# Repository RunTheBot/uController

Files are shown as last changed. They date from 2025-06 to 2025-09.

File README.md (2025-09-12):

# µController

µController (micro controller) a tiny battery powered game controller design for one game...unrailed

This way, you can ruin friendships with unrailed anywhere, anytime.



final
# Features
- Hall effect PS4 style joysticks
- 2 Cherry MX keys for use and dash inputs
- Neopixel RGB LED under Cherry MX keys
- 5v boost converter for neopixel running off 3.7v battery
- USB-C charging port
- Battery charging
- Battery voltage sensor
- Battery level indicator
- Ultra low power mode
  - Deep sleep mode with wake on button press
  - Disables boost converter and neopixel
  - Disables Wireless connection
- Ultra Small: 79mm x 33mm
- Wireless

# BOM

| Name | Quantity | Single Unit Price | Total Price | URL/LCSC | Vendor (LCSC unless otheriwse indicated) | |
|---|---|---|---|---|---|---|
| Electronics | | | | | | |
| C5 0603 0.1uF | 3 | | $0.45 | C49678 | | |
| C3 0603 10uF | 1 | | $0.13 | C19702 | | |
| C4 0603 22uF | 1 | | $0.18 | C59461 | | |
| LED 0603 | 1 | | $0.32 | C965799 | | |
| SK6812MINI | 2 | | $0.37 | C5149201 | | |
| schottky diode | 2 | | | C85098 | | With NotAHackPad |
| BSS138 (Level Shifter) | 1 | | | C82045 | | With NotAHackPad |
| USB_C_Receptacle | 1 | | $0.38 | C2988369 | | |
| 2.2µH/±20%/1.5A Inductor | 1 | | $0.67 | C171762 | | |
| 0603 R5.1kΩ | 2 | | $0.09 | C2907044 | | |
| 0603 1.8M | 1 | | $0.08 | C2930026 | | |
| 0603 200k | 1 | | $0.12 | C105574 | | |
| 0603 120Ω | 1 | | $0.13 | C114640 | | |
| 0603 10K | 3 | | | C98220 | With NotAHackPad | |
| 0603 15kΩ | 1 | | $0.09 | C2906995 | | |
| 0603 100kΩ | 2 | | $0.10 | C14675 | | |
| SW_Push_SPST_NO_Alps_SKRK  | 2 | | $0.63 | C115357 | | |
| NanoS3 | 1 | | $19.00 | https://unexpectedmaker.com/shop.html#!/NanoS3/p/577095557/category=154217256 | UM | |
| TPS61200DRC | 1 | | $1.63 | C140320 | | |
| PS4 Joystick Hall Effect | 1 | | $4.59 | https://www.aliexpress.com/item/1005008600410715.html | | |
| BT2.0 U CablePigtail (180) | 1 | | $8.20 | https://www.aliexpress.com/item/1005008719531779.html | | |
| Battery | 1 | | $25.79 | https://www.aliexpress.com/item/1005008702820863.html | | |
| LCSC Shipping/handling | | | $15.14 | | | |
| UM Shipping | | | $12.95 | | | |
| Keys | | | | | | |
| Outemu Silent Grays | 1 | $22.38 | $22.38 | https://www.aliexpress.com/item/1005007052759423.html | | |
| Key Caps - Printed | | | $0.00 | | | |
| JLC | | | | | | |
| PCB with stencil | 1 | $9.00 | $9.00 | | | |
| Shipping | 1 | $16.88 | $16.88 | | | |
| | | | | | | |
| | | | $60.96 | CAD | | |
| | | | $59.34 | USD | | |
| | | | $103.89 | Total - USD | | |

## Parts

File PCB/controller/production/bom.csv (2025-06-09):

Designator | Footprint | Quantity | Value | LCSC Part #
BT1 | JST_XH_S2B-XH-A_1x02_P2.50mm_Horizontal | 1 | Battery | C493111
C1, C2, C5 | 0805 | 3 | 0.1uF | C49678
C3 | 0603 | 1 | 10uF | C19702
C4 | 0603 | 1 | 22uF | C59461
D1 | 0603 | 1 | LED | C965799
D2, D3 | SK6812MINI-E | 2 | SK6812MINI | C5149201
D4, D5 | D_SMA-SMB_Universal_Handsoldering | 2 | D_Shockley | C85098
J1 | USB_C_Receptacle_XKB_U262-16XN-4BVC11 | 1 | USB_C_Receptacle_USB2.0_16P
L1 | 1008 | 1 | 2.2µH/±20%/1.5A | C2988369
Q5 | SOT-23 | 1 | BSS138 | C171762
R1, R2 | 0603 | 2 | R5.1k | C2907044
R10 | 0603 | 1 | 1.8M | C2930026
R11 | 0603 | 1 | 200k | C105574
R3 | 0603 | 1 | 120 | C114640
R4, R5, R6 | 0603 | 3 | 10K | C98220
R7 | 0603 | 1 | 15k | C2906995
R8, R9 | 0603 | 2 | 100k | C14675
SW2, SW3 | SW_Cherry_MX_PCB_1.00u | 2 | SW_Push
SW_BOOT1, SW_RESET1 | SW_Push_SPST_NO_Alps_SKRK | 2 | SW_Push | C115357
U1 | NanoS3_HandSolder | 1 | NanoS3
U2 | PS4_joystick | 1 | COM-09032
U3 | Texas_S-PVSON-N10_ThermalVias | 1 | TPS61200DRC | C140320

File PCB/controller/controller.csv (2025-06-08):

Reference | Qty | Value | DNP | Exclude from BOM | Exclude from Board | Footprint | Datasheet
BT1 | 1 | Battery |  |  |  | Connector_JST:JST_XH_S2B-XH-A_1x02_P2.50mm_Horizontal | ~
C1,C2 | 2 | C |  |  |  | Capacitor_SMD:C_0805_2012Metric_Pad1.18x1.45mm_HandSolder | ~
C3 | 1 | 10uF |  |  |  | Capacitor_SMD:C_0603_1608Metric_Pad1.08x0.95mm_HandSolder | ~
C4 | 1 | 22uF |  |  |  | Capacitor_SMD:C_0603_1608Metric_Pad1.08x0.95mm_HandSolder | ~
C5 | 1 | 0.1uF |  |  |  | Capacitor_SMD:C_0603_1608Metric_Pad1.08x0.95mm_HandSolder | ~
D1 | 1 | LED |  |  |  | LED_SMD:LED_0603_1608Metric_Pad1.05x0.95mm_HandSolder | ~
D2,D3 | 2 | SK6812MINI |  |  |  | footprints:SK6812MINI-E | https://cdn-shop.adafruit.com/product-files/2686/SK6812MINI_REV.01-1-2.pdf
D4,D5 | 2 | D_Shockley |  |  |  | Diode_SMD:D_SMA-SMB_Universal_Handsoldering | ~
J1 | 1 | USB_C_Receptacle_USB2.0_16P |  |  |  | Connector_USB:USB_C_Receptacle_XKB_U262-16XN-4BVC11 | https://www.usb.org/sites/default/files/documents/usb_type-c.zip
L1 | 1 | 2.2µH/±20%/1.5A |  |  |  | Inductor_SMD:L_1008_2520Metric_Pad1.43x2.20mm_HandSolder | ~
Q5 | 1 | BSS138 |  |  |  | Package_TO_SOT_SMD:SOT-23 | https://www.onsemi.com/pub/Collateral/BSS138-D.PDF
R1,R2 | 2 | R5.1kΩ |  |  |  | Resistor_SMD:R_0603_1608Metric_Pad0.98x0.95mm_HandSolder | ~
R3 | 1 | 120Ω |  |  |  | Capacitor_SMD:C_0603_1608Metric_Pad1.08x0.95mm_HandSolder | ~
R4,R5 | 2 | 10K |  |  |  | Resistor_SMD:R_0603_1608Metric_Pad0.98x0.95mm_HandSolder | ~
R6 | 1 | 10kΩ |  |  |  | Resistor_SMD:R_0603_1608Metric_Pad0.98x0.95mm_HandSolder | ~
R7 | 1 | 15kΩ |  |  |  | Resistor_SMD:R_0603_1608Metric_Pad0.98x0.95mm_HandSolder | ~
R8,R9 | 2 | 100kΩ |  |  |  | Resistor_SMD:R_0603_1608Metric_Pad0.98x0.95mm_HandSolder | ~
R10 | 1 | 1.8M |  |  |  | Resistor_SMD:R_0603_1608Metric_Pad0.98x0.95mm_HandSolder | ~
R11 | 1 | 200k |  |  |  | Resistor_SMD:R_0603_1608Metric_Pad0.98x0.95mm_HandSolder | ~
SW2,SW3 | 2 | SW_Push |  |  |  | footprints:SW_Cherry_MX_PCB_1.00u | ~
SW_BOOT1,SW_RESET1 | 2 | SW_Push |  |  |  | Button_Switch_SMD:SW_Push_SPST_NO_Alps_SKRK | ~
U1 | 1 | NanoS3 |  |  |  | NanoS3:NanoS3_HandSolder
U2 | 1 | COM-09032 |  |  |  | footprints:PS4_joystick
U3 | 1 | TPS61200DRC |  |  |  | Package_SON:Texas_S-PVSON-N10_ThermalVias | http://www.ti.com/lit/ds/symlink/tps61200.pdf

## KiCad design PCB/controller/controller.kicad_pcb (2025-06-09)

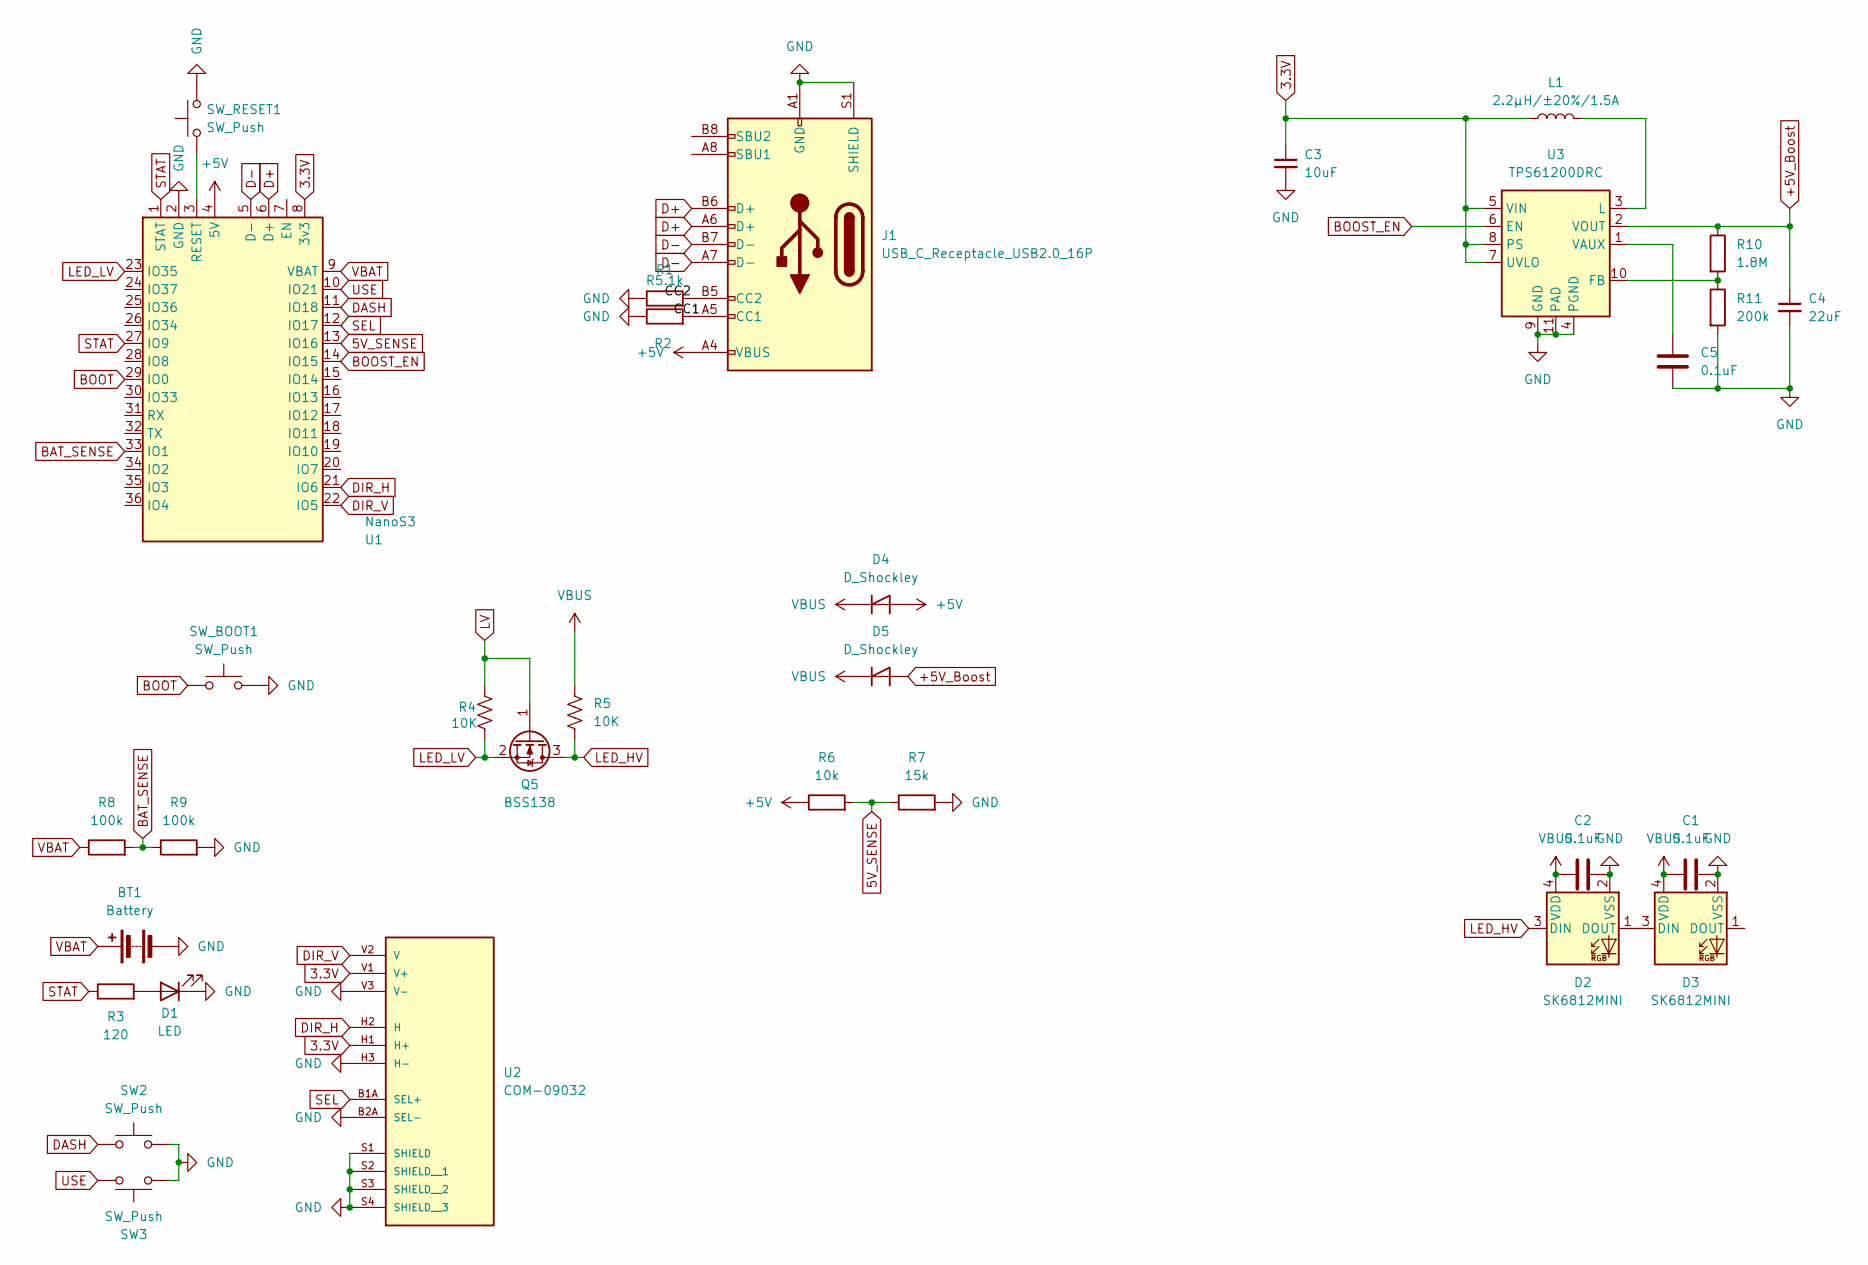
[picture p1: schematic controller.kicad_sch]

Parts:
BT1: Battery; JST_XH_S2B-XH-A_1x02_P2.50mm_Horizontal
C1, C2: 0.1uF; C_0805_2012Metric_Pad1.18x1.45mm_HandSolder
C3: 10uF; C_0603_1608Metric_Pad1.08x0.95mm_HandSolder
C4: 22uF; C_0603_1608Metric_Pad1.08x0.95mm_HandSolder
C5: 0.1uF; C_0603_1608Metric_Pad1.08x0.95mm_HandSolder
D1: LED; LED_0603_1608Metric_Pad1.05x0.95mm_HandSolder
D2, D3: SK6812MINI; SK6812MINI-E
D4, D5: D_Shockley; D_SMA-SMB_Universal_Handsoldering
J1: USB_C_Receptacle_USB2.0_16P; USB_C_Receptacle_G-Switch_GT-USB-7010ASV
L1: 2.2µH/±20%/1.5A; L_1008_2520Metric_Pad1.43x2.20mm_HandSolder
Q5: BSS138; SOT-23
R1, R2: R5.1k; R_0603_1608Metric_Pad0.98x0.95mm_HandSolder
R3: 120; C_0603_1608Metric_Pad1.08x0.95mm_HandSolder
R4, R5: 10K; R_0603_1608Metric_Pad0.98x0.95mm_HandSolder
R6: 10k; R_0603_1608Metric_Pad0.98x0.95mm_HandSolder
R7: 15k; R_0603_1608Metric_Pad0.98x0.95mm_HandSolder
R8, R9: 100k; R_0603_1608Metric_Pad0.98x0.95mm_HandSolder
R10: 1.8M; R_0603_1608Metric_Pad0.98x0.95mm_HandSolder
R11: 200k; R_0603_1608Metric_Pad0.98x0.95mm_HandSolder
SW2, SW3: SW_Push; SW_Cherry_MX_PCB_1.00u
SW_BOOT1: SW_Push; SW_Push_SPST_NO_Alps_SKRK
SW_RESET1: SW_Push; SW_Push_SPST_NO_Alps_SKRK
U1: NanoS3; NanoS3_HandSolder
U2: COM-09032; PS4_joystick; PARTREV N/A
U3: TPS61200DRC; Texas_S-PVSON-N10_ThermalVias

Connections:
3.3V: C3.1, L1.1, U1.8 (3v3), U2.H1 (H+), U2.V1 (V+), U3.5 (VIN), U3.7 (UVLO), U3.8 (PS)
5V_SENSE: R6.2, R7.1, U1.13 (IO16)
+5V: D4.2 (A), J1.A4 (VBUS), J1.A9 (VBUS), J1.B4 (VBUS), J1.B9 (VBUS), R6.1, U1.4 (5V)
+5V_Boost: C4.1, D5.2 (A), R10.1, U3.2 (VOUT)
/CC2: J1.B5 (CC2), R1.2
BAT_SENSE: R8.2, R9.1, U1.33 (IO1)
BOOST_EN: U1.14 (IO15), U3.6 (EN)
BOOT: SW_BOOT1.1, U1.29 (IO0)
D+: J1.A6 (D+), J1.B6 (D+), U1.6 (D+)
D-: J1.A7 (D-), J1.B7 (D-), U1.5 (D-)
DASH: SW2.1, U1.11 (IO18)
DIR_H: U1.21 (IO6), U2.H2 (H)
DIR_V: U1.22 (IO5), U2.V2 (V)
GND: BT1.2 (-), C1.2, C2.2, C3.2, C4.2, C5.1, D1.1 (K), D2.2 (VSS), D3.2 (VSS), J1.A1 (GND), J1.A12 (GND), J1.B1 (GND), J1.B12 (GND), J1.S1 (SHIELD), R1.1, R2.1, R7.2, R9.2, R11.2, SW2.2, SW3.1, SW_BOOT1.2, SW_RESET1.2, U1.2 (GND), U2.B2A (SEL-), U2.H3 (H-), U2.S1 (SHIELD), U2.S2 (SHIELD__1), U2.S3 (SHIELD__2), U2.S4 (SHIELD__3), U2.V3 (V-), U3.4 (PGND), U3.9 (GND), U3.11 (PAD)
LED_HV: D2.3 (DIN), Q5.3 (D), R5.2
LED_LV: Q5.2 (S), R4.2, U1.23 (IO35)
LV: Q5.1 (G), R4.1
unnamed: D1.2 (A), R3.2
unnamed: D2.1 (DOUT), D3.3 (DIN)
unnamed: J1.A5 (CC1), R2.2
unnamed: SW_RESET1.1, U1.3 (RESET)
unnamed: R10.2, R11.1, U3.10 (FB)
unnamed: L1.2, U3.3 (L)
unnamed: C5.2, U3.1 (VAUX)
SEL: U1.12 (IO17), U2.B1A (SEL+)
STAT: R3.1, U1.1 (STAT), U1.27 (IO9)
USE: SW3.2, U1.10 (IO21)
VBAT: BT1.1 (+), R8.1, U1.9 (VBAT)
VBUS: C1.1, C2.1, D2.4 (VDD), D3.4 (VDD), D4.1 (K), D5.1 (K), R5.1

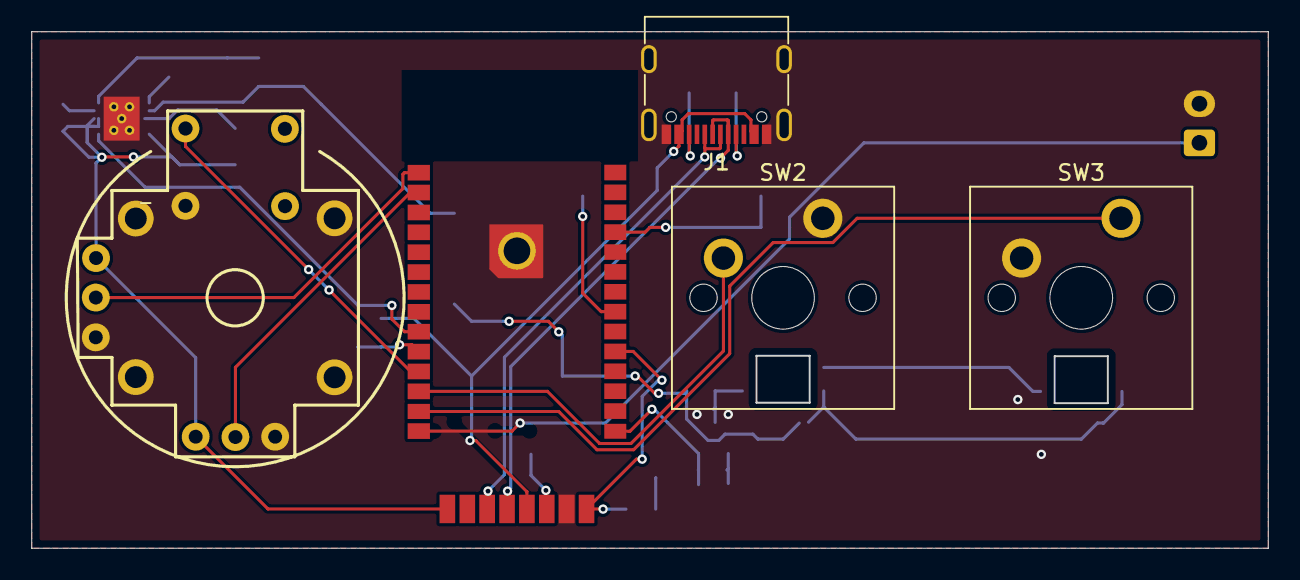
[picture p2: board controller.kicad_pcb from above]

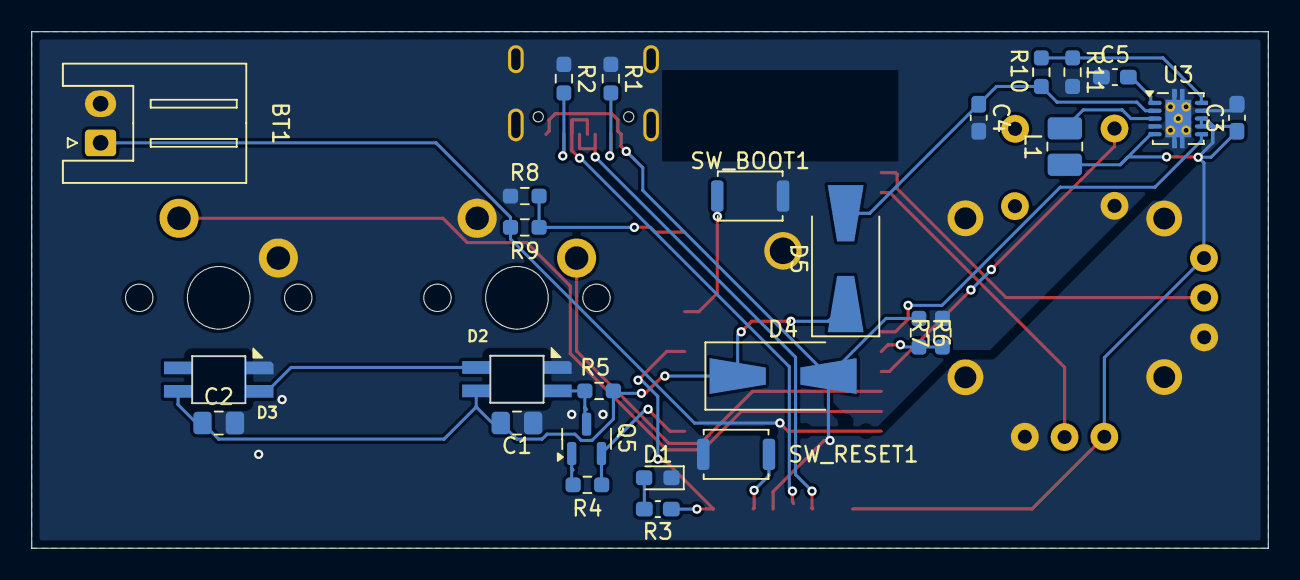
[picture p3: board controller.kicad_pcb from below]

Board: 2 copper layers, 79.0 x 33.0 mm, 32 parts (27 on the bottom side), 29 nets.

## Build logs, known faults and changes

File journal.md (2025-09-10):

---
title: "µController"
author: "RunTheBot"
description: "µController (micro controller) a tiny battery powered game controller design for one game...unrailed"
---

hours: 19h

# 06/04/2025

hours: 3h

Bunch of PCB progress. Layed out. Just need part sourcing and routing.






# 06/07/2025

hours: 2h

PCB routing is done. Some ammount of part sourcing is done. Need to finish sourcing the rest of the parts.


# 06/08/2025
hours: 12h

Added Boost converter to the PCB. For 5v rail on battery.


Added voltage divider for the battery voltage measurement and sense for usb power.



All fits nicely in the same size of the PCB.


CADing...






BOM and lots of minor fixes. I decided to go with a BetaFPV battery and a cable instead of a JST connector. 

# Firmware
hours: 3h

HID is painful. Just found a library to do it instead of writing it myself. I wasted a lot of time.

# June 29th
Hours: 2
Soldered the entire thing. I kinda broke the Nano s3 by overheating it sooooooo. I need to bodge wire a xiao in. I should have used it to start.
uController with another one of my projects

# Aug 2nd
Hours: 2h
Dodge wired it. Turns out one hall effect sensor doesn't work. Otherwise, it's completely working. I'm about to travel so demo time!

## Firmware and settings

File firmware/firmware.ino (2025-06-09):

/*
 * ESP32-S3 Bluetooth Controller Firmware for Unrailed
 * NanoS3/Tiny Pico Nano Compatible
 * 
 * Pin Configuration:
 * LED_LV      IO35 - Status LED
 * BAT_STAT    IO9  - Battery Status
 * BAT_SENSE   IO1  - Battery Voltage (Analog, 100k/100k divider)
 * USE         IO21 - Button A
 * DASH        IO18 - Button B
 * SEL         IO17 - Select Button
 * 5V_SENSE    IO16 - USB 5V Detection
 * BOOST_EN    IO15 - 5V Boost Enable
 * DIR_H       IO6  - Analog Joystick Horizontal (Left Stick X)
 * DIR_V       IO5  - Analog Joystick Vertical (Left Stick Y)
 * 
 * Controller Mapping:
 * - Analog joystick -> Left stick (X, Y)
 * - USE button -> A button (BUTTON_1)
 * - DASH button -> B button (BUTTON_2)
 * - SEL button -> Select
 */

#include <Arduino.h>
#include <BleGamepad.h>
#include "controller_config.h"
#include "esp_sleep.h"
#include "driver/rtc_io.h"

// Pin definitions - now using config file
// (All pin definitions moved to controller_config.h)

// Button states
bool useButtonState = false;
bool dashButtonState = false;
bool selButtonState = false;
bool lastUseButtonState = false;
bool lastDashButtonState = false;
bool lastSelButtonState = false;

// Joystick calibration
int16_t joystickCenterX = JOYSTICK_CENTER;
int16_t joystickCenterY = JOYSTICK_CENTER;
int16_t joystickDeadzone = JOYSTICK_DEADZONE;

// Battery monitoring
float batteryVoltage = 0.0;
uint8_t batteryPercentage = 100;
unsigned long lastBatteryCheck = 0;
const unsigned long batteryCheckInterval = BATTERY_CHECK_INTERVAL;

// Sleep management
unsigned long lastActivityTime = 0;
bool lowBatteryMode = false;
int16_t lastJoystickX = 0;
int16_t lastJoystickY = 0;
RTC_DATA_ATTR int bootCount = 0;

BleGamepad bleGamepad(CONTROLLER_NAME, MANUFACTURER, 100);

void setup()
{
    Serial.begin(115200);
    
    // Check wake up reason
    bootCount++;
    esp_sleep_wakeup_cause_t wakeup_reason = esp_sleep_get_wakeup_cause();
    
    Serial.printf("Boot count: %d\n", bootCount);
    Serial.printf("Wake up reason: %d\n", wakeup_reason);
    
    if (wakeup_reason == ESP_SLEEP_WAKEUP_EXT1) {
        Serial.println("Woke up from button press");
    } else {
        Serial.println("Fresh boot or unknown wake reason");
    }
    
    Serial.println("Starting Unrailed Controller...");
    
    // Initialize pins
    pinMode(LED_LV_PIN, OUTPUT);
    pinMode(BAT_STAT_PIN, INPUT);
    pinMode(USE_PIN, INPUT_PULLUP);
    pinMode(DASH_PIN, INPUT_PULLUP);
    pinMode(SEL_PIN, INPUT_PULLUP);
    pinMode(USB_5V_SENSE, INPUT);
    pinMode(BOOST_EN_PIN, OUTPUT);
    
    // Enable boost for 5V output when on battery
    digitalWrite(BOOST_EN_PIN, HIGH);
    
    // LED startup sequence
    for(int i = 0; i < LED_STARTUP_BLINKS; i++) {
        digitalWrite(LED_LV_PIN, HIGH);
        delay(200);
        digitalWrite(LED_LV_PIN, LOW);
        delay(200);
    }
    
    // Configure wake up sources for deep sleep
    configureSleepWakeup();
    
    // Calibrate joystick center position
    calibrateJoystick();
    
    // Initialize activity timer
    lastActivityTime = millis();
    
    // Start BLE gamepad
    bleGamepad.begin();
    Serial.println("Controller initialized!");
}

void loop()
{
    // Read button states (active low with pullup)
    useButtonState = !digitalRead(USE_PIN);
    dashButtonState = !digitalRead(DASH_PIN);
    selButtonState = !digitalRead(SEL_PIN);
    
    // Handle button presses/releases
    if (useButtonState != lastUseButtonState) {
        if (useButtonState) {
            bleGamepad.press(GAMEPAD_BUTTON_A);
            Serial.println("A button pressed");
            updateActivityTime();
        } else {
            bleGamepad.release(GAMEPAD_BUTTON_A);
            Serial.println("A button released");
        }
        lastUseButtonState = useButtonState;
    }
    
    if (dashButtonState != lastDashButtonState) {
        if (dashButtonState) {
            bleGamepad.press(GAMEPAD_BUTTON_B);
            Serial.println("B button pressed");
            updateActivityTime();
        } else {
            bleGamepad.release(GAMEPAD_BUTTON_B);
            Serial.println("B button released");
        }
        lastDashButtonState = dashButtonState;
    }
    
    if (selButtonState != lastSelButtonState) {
        if (selButtonState) {
            bleGamepad.pressSelect();
            Serial.println("Select button pressed");
            updateActivityTime();
        } else {
            bleGamepad.releaseSelect();
            Serial.println("Select button released");
        }
        lastSelButtonState = selButtonState;
    }
    
    // Read and process joystick
    processJoystick();
    
    // Battery monitoring
    if (millis() - lastBatteryCheck > batteryCheckInterval) {
        checkBattery();
        lastBatteryCheck = millis();
    }
    
    // Update LED status
    updateStatusLED();
    
    // Check for sleep conditions
    checkSleepConditions();
    
    delay(10); // Small delay for stability
}

void calibrateJoystick() {
    Serial.println("Calibrating joystick center position...");
    
    // Take multiple readings to get stable center values
    long totalX = 0, totalY = 0;
    int samples = 100;
    
    for (int i = 0; i < samples; i++) {
        totalX += analogRead(DIR_H_PIN);
        totalY += analogRead(DIR_V_PIN);
        delay(10);
    }
    
    joystickCenterX = totalX / samples;
    joystickCenterY = totalY / samples;
    
    Serial.printf("Joystick center: X=%d, Y=%d\n", joystickCenterX, joystickCenterY);
}

void processJoystick() {
    // Read raw ADC values (0-4095 for 12-bit)
    int rawX = analogRead(DIR_H_PIN);
    int rawY = analogRead(DIR_V_PIN);
    
    // Calculate relative position from center
    int deltaX = rawX - joystickCenterX;
    int deltaY = rawY - joystickCenterY;
    
    // Apply deadzone
    if (abs(deltaX) < joystickDeadzone) deltaX = 0;
    if (abs(deltaY) < joystickDeadzone) deltaY = 0;
    
    // Convert to gamepad range (-32768 to 32767)
    int16_t gamepadX = map(deltaX, -2048, 2047, -32768, 32767);
    int16_t gamepadY = map(deltaY, -2048, 2047, -32768, 32767);
    
    // Invert Y axis (joystick up = negative Y in gamepad coordinates)
    gamepadY = -gamepadY;
    
    // Check for joystick activity
    if (abs(gamepadX - lastJoystickX) > ACTIVITY_THRESHOLD || 
        abs(gamepadY - lastJoystickY) > ACTIVITY_THRESHOLD) {
        updateActivityTime();
        lastJoystickX = gamepadX;
        lastJoystickY = gamepadY;
    }
    
    // Set left stick position
    bleGamepad.setLeftThumb(gamepadX, gamepadY);
}

void checkBattery() {
    // Read battery voltage through voltage divider
    int adcValue = analogRead(BAT_SENSE_PIN);
    
    // Convert ADC to voltage (3.3V reference, 12-bit ADC, voltage divider)
    batteryVoltage = (adcValue * 3.3 * VOLTAGE_DIVIDER_RATIO) / 4095.0;
    
    // Convert voltage to percentage (approximate for Li-Po)
    batteryPercentage = constrain(map(batteryVoltage * 100, 
                                     BATTERY_MIN_VOLTAGE * 100, 
                                     BATTERY_MAX_VOLTAGE * 100, 
                                     0, 100), 0, 100);
    
    // Update gamepad battery level
    bleGamepad.setBatteryLevel(batteryPercentage);
    
    // Check for low battery mode
    if (batteryPercentage <= LOW_BATTERY_THRESHOLD && !digitalRead(USB_5V_SENSE)) {
        lowBatteryMode = true;
        Serial.println("Entering low battery mode");
    } else {
        lowBatteryMode = false;
    }
    
    // Check if USB power is available
    bool usbPowered = digitalRead(USB_5V_SENSE);
    
    // Enable/disable boost based on USB power
    if (usbPowered) {
        digitalWrite(BOOST_EN_PIN, LOW);  // Disable boost when USB powered
    } else {
        digitalWrite(BOOST_EN_PIN, HIGH); // Enable boost on battery
    }
    
    Serial.printf("Battery: %.2fV (%d%%) USB: %s\n", 
                  batteryVoltage, batteryPercentage, usbPowered ? "Yes" : "No");
}

void updateStatusLED() {
    static unsigned long lastLedUpdate = 0;
    static bool ledState = false;
    
    if (bleGamepad.isConnected()) {
        // Solid on when connected
        digitalWrite(LED_LV_PIN, HIGH);
    } else {
        // Blink when not connected
        if (millis() - lastLedUpdate > LED_BLINK_INTERVAL) {
            ledState = !ledState;
            digitalWrite(LED_LV_PIN, ledState);
            lastLedUpdate = millis();
        }
    }
}

// Deep sleep and power management functions

void updateActivityTime() {
    lastActivityTime = millis();
}

void configureSleepWakeup() {
    // Configure wake up sources
    // Wake up ONLY when ALL 3 buttons are pressed simultaneously (WAKEUP_ALL_LOW)
    esp_sleep_enable_ext1_wakeup(WAKE_BUTTON_BITMASK, ESP_EXT1_WAKEUP_ALL_LOW);
    
    // Configure RTC IO for wake up buttons (pullup for ALL_LOW mode)
    rtc_gpio_pullup_en((gpio_num_t)USE_PIN);
    rtc_gpio_pullup_en((gpio_num_t)DASH_PIN);
    rtc_gpio_pullup_en((gpio_num_t)SEL_PIN);
    
    Serial.println("Sleep wake-up sources configured - requires all 3 buttons pressed");
}

void checkSleepConditions() {
    unsigned long inactiveTime = millis() - lastActivityTime;
    bool usbConnected = digitalRead(USB_5V_SENSE);
    
    // Don't sleep if USB is connected (for debugging/charging)
    if (usbConnected) {
        return;  
    }
    
    // Check if we should enter deep sleep
    bool shouldSleep = false;
    
    if (lowBatteryMode) {
        // In low battery mode, sleep more aggressively
        if (inactiveTime > 30000) { // 30 seconds
            shouldSleep = true;
            Serial.println("Entering deep sleep - low battery mode");
        }
    } else if (!bleGamepad.isConnected()) {
        // If not connected, sleep after 2 minutes
        if (inactiveTime > 120000) { // 2 minutes
            shouldSleep = true;  
            Serial.println("Entering deep sleep - not connected");
        }
    } else {
        // If connected but inactive, sleep after 5 minutes
        if (inactiveTime > SLEEP_TIMEOUT_MS) {
            shouldSleep = true;
            Serial.println("Entering deep sleep - inactive while connected");
        }
    }
    
    if (shouldSleep) {
        enterDeepSleep();
    }
}

void enterDeepSleep() {
    Serial.println("Preparing for deep sleep...");
    
    // Flash LED to indicate sleep
    for (int i = 0; i < 5; i++) {
        digitalWrite(LED_LV_PIN, HIGH);
        delay(100);
        digitalWrite(LED_LV_PIN, LOW);
        delay(100);
    }
    
    // Disconnect BLE gracefully
    if (bleGamepad.isConnected()) {
        Serial.println("Disconnecting BLE...");
        bleGamepad.end();
        delay(1000); // Give time for disconnection
    }
    
    // Turn off boost converter to save power
    digitalWrite(BOOST_EN_PIN, LOW);
    
    // Turn off LED
    digitalWrite(LED_LV_PIN, LOW);
    
    Serial.println("Entering deep sleep now...");
    Serial.flush(); // Ensure all serial data is sent
    
    // Enter deep sleep
    esp_deep_sleep_start();
}

void handleWakeup() {
    esp_sleep_wakeup_cause_t wakeup_reason = esp_sleep_get_wakeup_cause();
    
    switch (wakeup_reason) {
        case ESP_SLEEP_WAKEUP_EXT1:
            Serial.println("Wake up from button press");
            // Reset activity timer since user pressed a button
            updateActivityTime();
            break;
            
        default:
            Serial.println("Wake up from unknown source");
            break;
    }
}

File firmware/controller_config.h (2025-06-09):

/*
 * ESP32-S3 Unrailed Controller Configuration
 * Hardware: NanoS3/Tiny Pico Nano
 */

#ifndef CONTROLLER_CONFIG_H
#define CONTROLLER_CONFIG_H

// Hardware version
#define HARDWARE_VERSION "NanoS3/Tiny Pico Nano"
#define FIRMWARE_VERSION "1.0.0"

// Pin definitions for ESP32-S3
#define LED_LV_PIN      35  // Status LED
#define BAT_STAT_PIN    9   // Battery Status Input
#define BAT_SENSE_PIN   1   // Battery Voltage ADC (100k/100k divider)
#define USE_PIN         21  // Button A (USE)
#define DASH_PIN        18  // Button B (DASH)
#define SEL_PIN         17  // Select Button
#define USB_5V_SENSE    16  // USB 5V Detection
#define BOOST_EN_PIN    15  // 5V Boost Enable
#define DIR_H_PIN       6   // Joystick Horizontal (X-axis)
#define DIR_V_PIN       5   // Joystick Vertical (Y-axis)

// Controller settings
#define CONTROLLER_NAME "Unrailed Controller"
#define MANUFACTURER    "ESP32"

// Joystick configuration
#define JOYSTICK_DEADZONE     100   // ADC units
#define JOYSTICK_CENTER       2048  // 12-bit ADC center
#define JOYSTICK_MAX_RANGE    2048  // Maximum deviation from center

// Battery configuration
#define BATTERY_CHECK_INTERVAL 5000  // milliseconds
#define BATTERY_MIN_VOLTAGE    3.0   // Volts
#define BATTERY_MAX_VOLTAGE    4.2   // Volts (fully charged Li-Po)
#define VOLTAGE_DIVIDER_RATIO  2.0   // 100k/100k = 2:1 ratio

// LED patterns
#define LED_BLINK_INTERVAL    500   // milliseconds (when not connected)
#define LED_STARTUP_BLINKS    3     // Number of blinks on startup

// Deep sleep configuration
#define SLEEP_TIMEOUT_MS         300000  // 5 minutes of inactivity before sleep
#define LOW_BATTERY_SLEEP_MS     30000   // 30 seconds between wake cycles when low battery
#define ACTIVITY_THRESHOLD       50      // Joystick movement threshold to detect activity
#define LOW_BATTERY_THRESHOLD    15      // Battery percentage threshold for extended sleep

// Wake up sources - Require ALL 3 buttons pressed simultaneously
#define WAKE_BUTTON_BITMASK      0x2A0000  // USE (GPIO21), DASH (GPIO18), and SEL (GPIO17) buttons
// Bitmask calculation: (1ULL << USE_PIN) | (1ULL << DASH_PIN) | (1ULL << SEL_PIN) 
// = (1ULL << 21) | (1ULL << 18) | (1ULL << 17) = 0x2A0000

// Button mapping for Unrailed game
typedef enum {
    GAMEPAD_BUTTON_A = 1,      // USE button -> A
    GAMEPAD_BUTTON_B = 2,      // DASH button -> B
    GAMEPAD_BUTTON_SELECT = 8  // SEL button -> Select
} GamepadButtons;

// Joystick mapping
typedef enum {
    JOYSTICK_LEFT_X = 0,   // DIR_H -> Left stick X
    JOYSTICK_LEFT_Y = 1    // DIR_V -> Left stick Y (inverted)
} JoystickAxes;

#endif // CONTROLLER_CONFIG_H

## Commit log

2025-06-07 Add lock files for PCB controller and schematic with user information
    [controller.kicad_pcb, controller.kicad_sch]
2025-06-08 Refactor code structure for improved readability and maintainability
    [controller.csv, controller.kicad_pcb]
2025-06-09 Add production files for PCB controller design
    - Created designators.csv with component designators and their counts.
    - Added netlist.ipc containing detailed netlist information for PCB connections.
    - Introduced positions.csv to specify component positions, rotations, and layers on the PCB.
    [bom.csv, controller.kicad_pcb, controller.kicad_sch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]
2025-06-09 Add BOM file for µController with component details and pricing
    [µController - BOM - LCSC.csv]
2025-06-09 Add lock file for PCB controller with hostname and username information
    [controller.kicad_pcb, controller.kicad_sch]
